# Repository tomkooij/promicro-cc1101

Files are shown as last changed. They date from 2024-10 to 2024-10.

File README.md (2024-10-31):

# e07-900m10s adapter board for Arduino Pro Micro (and esp32c3)
Adapter board for [ebyte e07-900m10s CC1101 module](https://www.ebyte.com/en/product-view-news.html?id=1567) and Arduino Pro Micro.

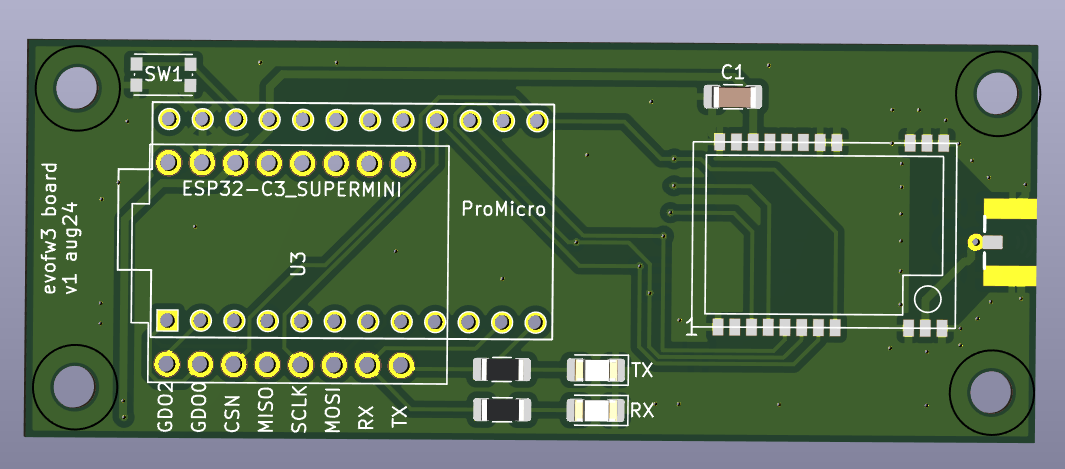
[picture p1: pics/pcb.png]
pcb


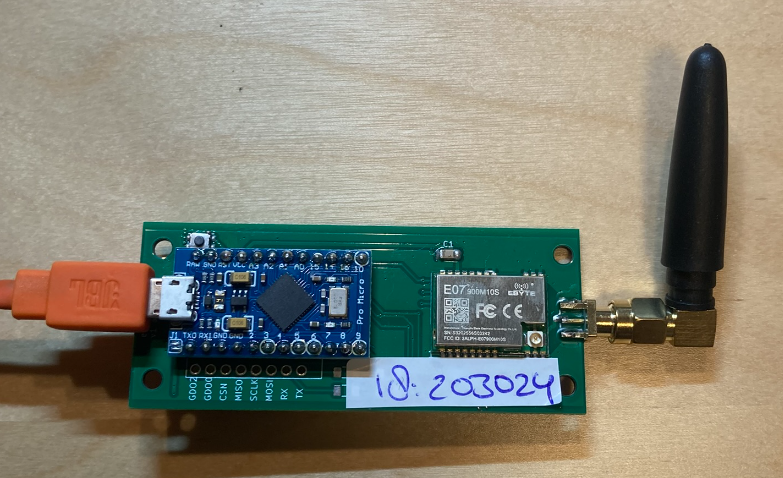
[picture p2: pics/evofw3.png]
assembled board

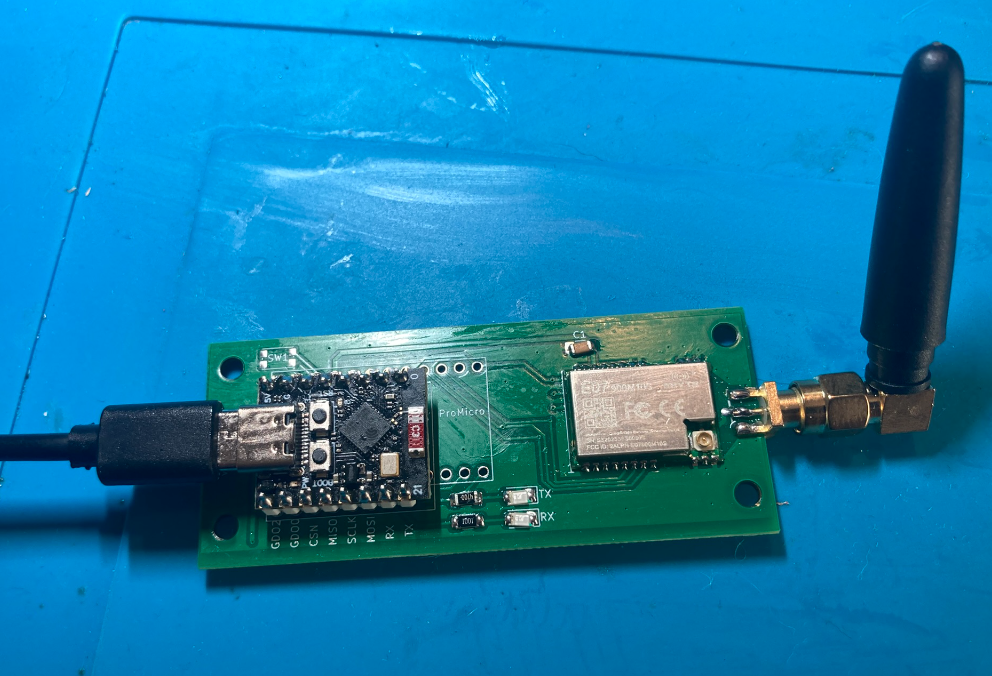
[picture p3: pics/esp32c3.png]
esp32c3


Using [evofw3](https://github.com/ghoti/evofw3) this is an Honeywell HGI-80 clone, that can be used to control Itho/Orcon fans (and evohome devices).
Use the [ramses_cc](https://github.com/zxdavb/ramses_cc) Home Assitant integration.

 - Arduino Pro Micro: mount the reset switch. The RX/TX LEDs are not used: The Pro Micro has on-board leds that are used by evofe3.
 - ESP32-C3: Optionally mount the RX/TX leds. Reset button is on-board. This can run ramses ESP.

TODO (improve in next version):
 - esp32c3 mosi/sclk/miso is reversed as compared my other boards MOSI = 10, SCLK 9... GPO2 5
   (pcb silkscreen is correct)
 - pro micro GND pins next to TX/RX are not connected to pcb GND plane

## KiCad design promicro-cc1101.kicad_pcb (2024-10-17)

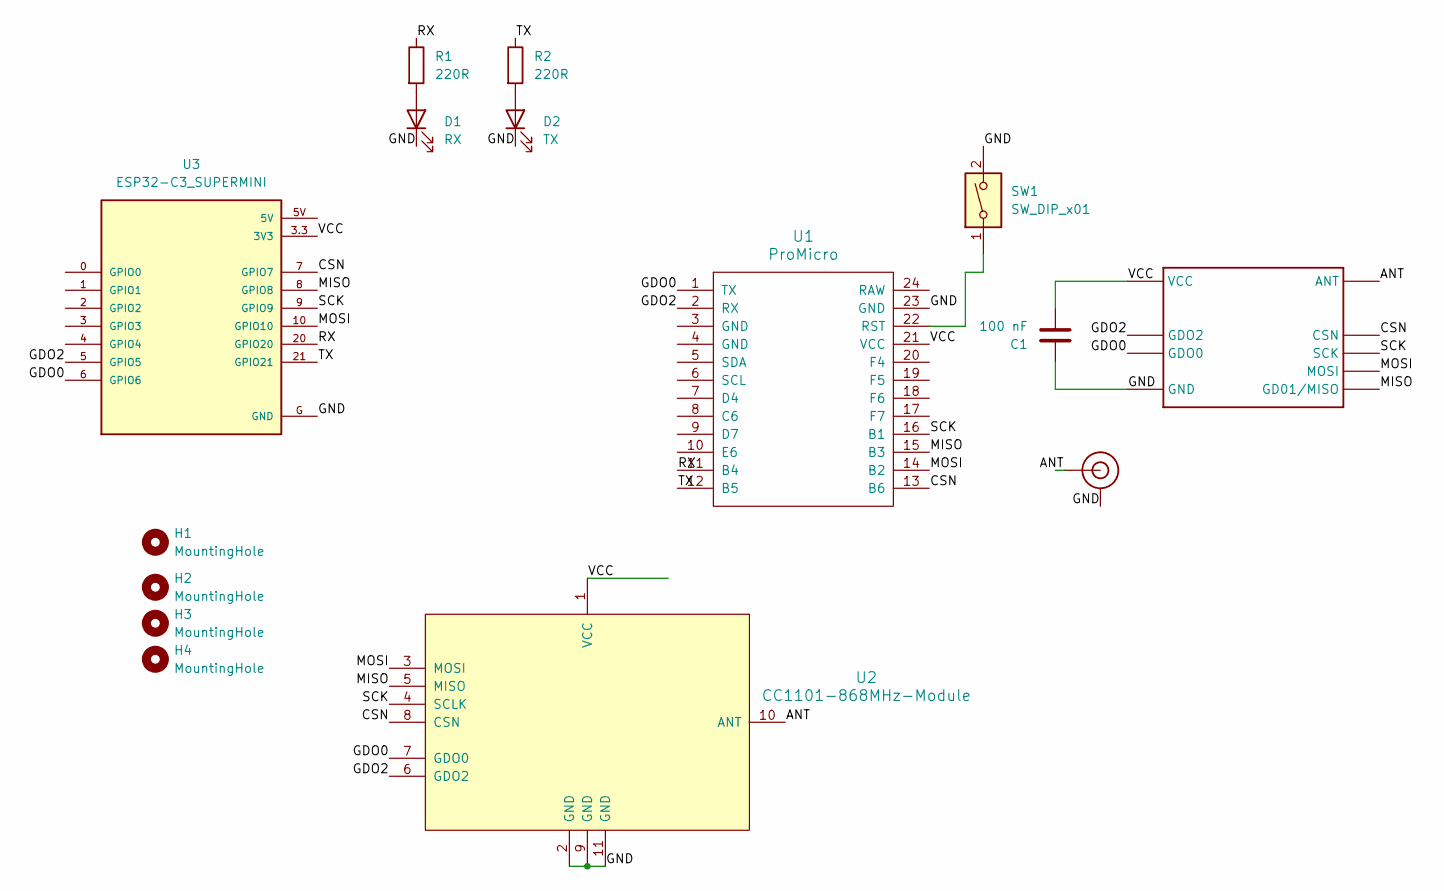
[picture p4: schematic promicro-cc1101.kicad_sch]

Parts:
1: E07-900M10S
C1: 100 nF; C_1206_3216Metric_Pad1.33x1.80mm_HandSolder
D1: RX; LED_1206_3216Metric_Pad1.42x1.75mm_HandSolder
D2: TX; LED_1206_3216Metric_Pad1.42x1.75mm_HandSolder
H1, H2, H3, H4: MountingHole; MountingHole_3.2mm_M3
J$1: SMA_PAD
R1, R2: 220R; R_1206_3216Metric_Pad1.30x1.75mm_HandSolder
SW1: SW_DIP_x01; SW_Push_1P1T_NO_CK_KMR2
U1: ProMicro
U2: CC1101-868MHz-Module
U3: ESP32-C3_SUPERMINI; MODULE_ESP32-C3_SUPERMINI

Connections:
/ANT: 1.21 (ANT), J$1.ANT0 (ANT), J$1.ANT1 (ANT), J$1.ANT2 (ANT), U2.10 (ANT)
/CSN: 1.19 (CSN), U1.13 (B6), U2.8 (CSN), U3.7 (GPIO7)
/GDO0: 1.15 (GDO0), U1.1 (TX), U2.7 (GDO0), U3.6 (GPIO6)
/GDO2: 1.14 (GDO2), U1.2 (RX), U2.6 (GDO2), U3.5 (GPIO5)
/GND: 1.1 (GND), 1.2 (GND), 1.3 (GND), 1.4 (GND), 1.5 (GND), 1.11 (GND), 1.12 (GND), 1.20 (GND), 1.22 (GND), C1.1, D1.1 (K), D2.1 (K), J$1.GND3 (GND), J$1.GND4 (GND), J$1.GND5 (GND), J$1.GND6 (GND), SW1.2, U1.23 (GND), U2.2 (GND), U2.9 (GND), U2.11 (GND), U3.G (GND)
/MISO: 1.16 (GD01/MISO), U1.15 (B3), U2.5 (MISO), U3.8 (GPIO8)
/MOSI: 1.17 (MOSI), U1.14 (B2), U2.3 (MOSI), U3.10 (GPIO10)
/RX: R1.1, U1.11 (B4), U3.20 (GPIO20)
/SCK: 1.18 (SCK), U1.16 (B1), U2.4 (SCLK), U3.9 (GPIO9)
/TX: R2.1, U1.12 (B5), U3.21 (GPIO21)
/VCC: 1.9 (VCC), C1.2, U1.21 (VCC), U2.1 (VCC), U3.3.3 (3V3)
unnamed: D1.2 (A), R1.2
unnamed: D2.2 (A), R2.2
unnamed: SW1.1, U1.22 (RST)

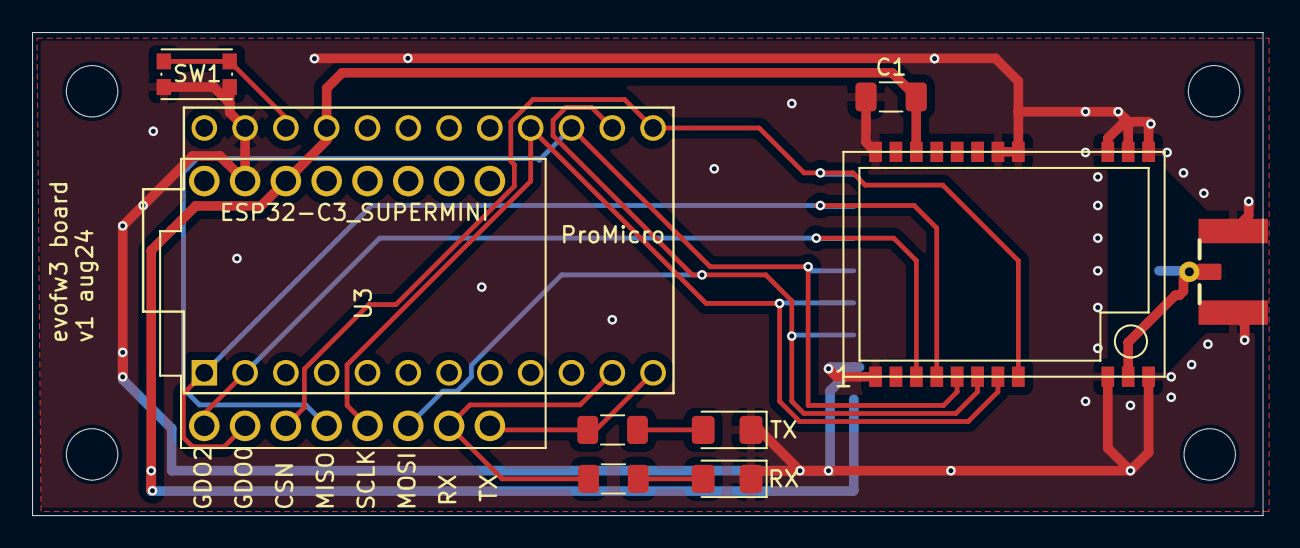
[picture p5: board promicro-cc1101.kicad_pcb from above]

Board: 2 copper layers, 76.6 x 30.1 mm, 15 parts (1 on the bottom side), 14 nets.
